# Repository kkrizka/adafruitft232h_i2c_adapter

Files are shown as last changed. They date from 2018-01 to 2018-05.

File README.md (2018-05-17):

Image of Device

# Introduction
The [FT232H](http://www.ftdichip.com/Products/ICs/FT232H.htm) is a funky little chip that converts from USB to random serial protocols. It is useful for talking to devices that communicate via I2C or SPI. Adafruit has developed a [FT232H break-out board](https://learn.adafruit.com/adafruit-ft232h-breakout/) that connects to a computer using a micro-USB port. However to use it with I2C, some external electronics are required.
 
The Adafruit FT232H I2C Adapter is a custom PCB that connects to the break-out board and adds
* fuses the FT232H input pin with the output pin for the bi-directional SDA line,
* contains an LDO to generate the reference voltage from the USB power,
* pull-up resistors to the reference voltage.

The reference voltage can be set by picking the right resistor values, allowing for a wide operational range.

# Components

* **U1**: 2x [0.1" 1x10 pin sockets](https://www.digikey.com/products/en?keywords=s7043-ND) to connect the the Adafruit FT232H break-out board
* **U2**: [ADP123 LDO](https://www.digikey.com/products/en?keywords=12T2968), TSOT-5 package
* **C1-2**: Bypass capacitors, 1 uF
* **R1-R2**: Pull-up resistors, 2 kOhm
* **R3-R4**: Output of U2 LDO set I2C reference voltage. `Vout = 0.5V (1 + R3/R4)`.
* **J1**: Connectors to the I2C device. 4 0.1" 1x4 pin header recommended.

# FT232H Open Drain Pins
By default, the FT232H device is configured in the `RS232` mode. In thise mode, the D0, D1 and D2 pins (used for I2C communication) are driven internally at 3.3V. To take advantage of the external variable reference mode, they need to be put into open-drain mode. The Adafruit board contains an EEPROM that that configures the device on power-up. It has to be configured using the [FT_PROG](http://www.ftdichip.com/Support/Utilities.htm#FT_PROG) (Windows only) tool.

To use open-drain for the I2C pins, set the mode as `245 FIFO`. This setting can be found under
```
Device
 -> FT EEPROM
   -> Hardware Specific
     -> 245 FIFO
```

FT_PROG Settings

# Device Permissions
The device permissions need to be loosened to allow usage of the libftdi driver as a non-root user. The following udev rule allow any user in the `plugdev` group to access the FTDI232H device. 

```
SUBSYSTEMS=="usb", ATTRS{idVendor}=="0403", ATTRS{idProduct}=="6014", MODE:="0666", GROUP:="plugdev"
```

Add it to a file called `/etc/udev/rules.d/83-ftdi.rules` and run the following command to load it:
```shell
udevadm control --reload-rules && udevadm trigger
```

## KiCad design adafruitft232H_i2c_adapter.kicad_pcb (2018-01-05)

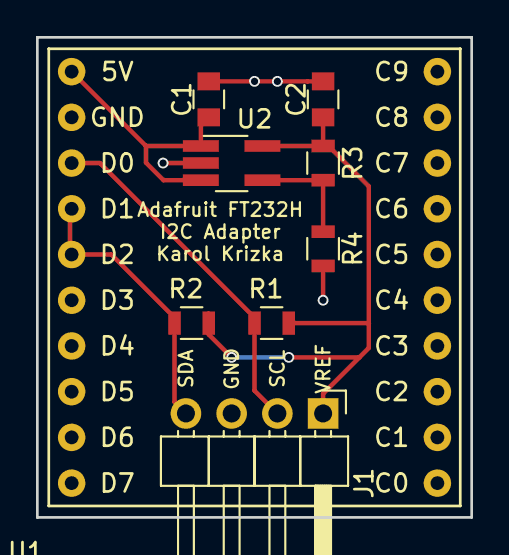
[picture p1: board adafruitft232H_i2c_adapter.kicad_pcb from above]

Board: 2 copper layers, 24.1 x 26.7 mm, 9 parts (0 on the bottom side), 6 nets.

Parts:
C1, C2: 1uF; C_0805
J1: CONN_01X04; Pin_Header_Angled_1x04_Pitch2.54mm
R1, R2, R3, R4: R; R_0805
U1: adafruit_ft232h; adafruit_ft232h_nohole
U2: APD123; TSOT-23-5_HandSoldering

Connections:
/5V: C1.1, U1.1, U2.1, U2.3
/SCL: J1.2, R1.2, U1.3
/SDA: J1.4, R2.2, U1.4, U1.5
/VREF: C2.1, J1.1, R1.1, R2.1, R3.1, U2.5
GND: C1.2, C2.2, J1.3, R4.2, U1.2, U2.2
unnamed: R3.2, R4.1, U2.4

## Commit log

2018-01-04 Import empty project.
    [adafruitft232H_i2c_adapter.kicad_pcb, adafruitft232H_i2c_adapter.sch]
2018-01-04 Schematic done.
    [adafruitft232H_i2c_adapter.sch]
2018-01-04 Add fp-lib-table?
    [adafruitft232H_i2c_adapter.kicad_pcb, adafruitft232H_i2c_adapter.sch]
2018-01-05 Small layout updates to make silkscreen prettier. Add gerbers.
    [adafruitft232H_i2c_adapter-B.Cu.gbr, adafruitft232H_i2c_adapter-B.Mask.gbr, adafruitft232H_i2c_adapter-B.SilkS.gbr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]
2018-01-05 Remove extra wires.
    [adafruitft232H_i2c_adapter.sch]
2018-01-05 Add name and title.
    [adafruitft232H_i2c_adapter.sch]
